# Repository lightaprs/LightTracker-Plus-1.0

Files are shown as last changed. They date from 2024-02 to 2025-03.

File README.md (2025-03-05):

# LightTracker Plus

LightTracker Plus is an ESP32-based development board featuring a 1 Watt SX1268 (433MHz) LoRa module, GPS module, battery holder, and 2 dBi 433 MHz SMA antenna.

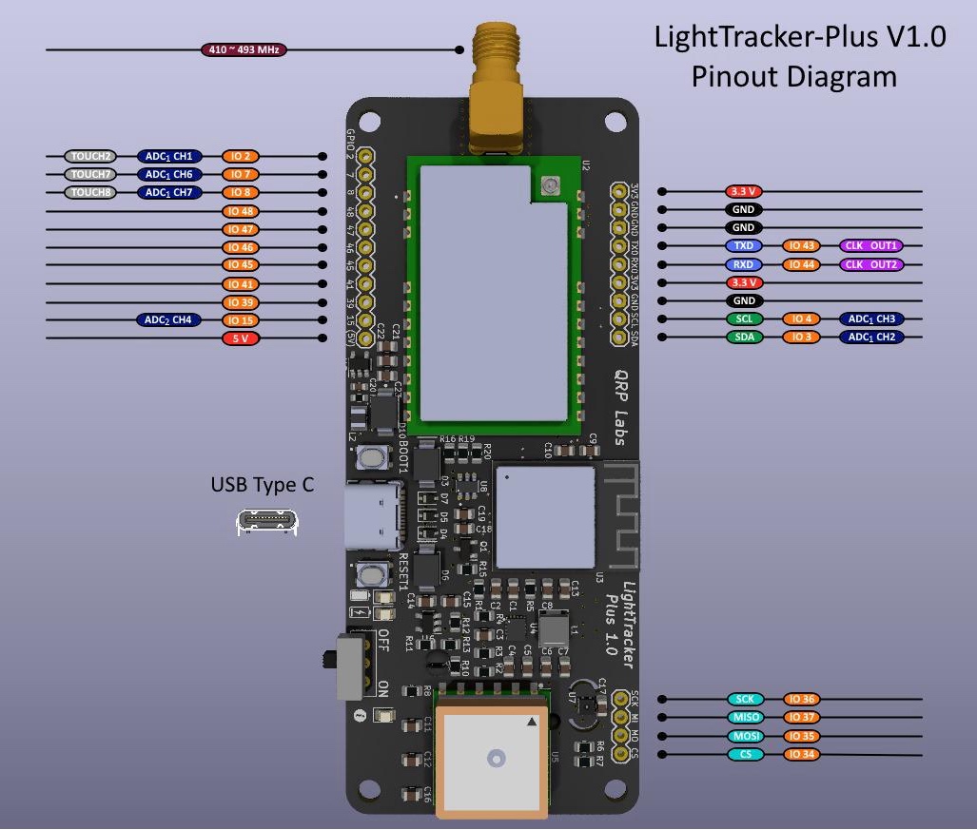
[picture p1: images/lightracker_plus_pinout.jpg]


LightTracker Plus is available on [https://shop.qrp-labs.com/aprs/lighttrackerplus](https://shop.qrp-labs.com/aprs/lighttrackerplus) for order.

If you need a Solar powered module for iGate or Digipeater check out : https://github.com/lightaprs/LightGatewayPlus-1.0

**Important :** LightTracker Plus 1.0 operates on the amateur 70 cm (UHF) radio band with a 30 dBm output power, which typically requires an amateur radio license to operate in many countries. Therefore, if you are not a licensed HAM operator, please ensure to check local regulations and laws before purchasing the module.

## Key Benefits

- Low Power Consumption Capability (Deep Sleep)
- Powerful (1 Watt) LoRa Radio Module
- Compact GPS Module Integrated with Patch Antenna
- GPS Balloon mode, for high altitude up to 80km (Convenient for High Altitude Balloon tracking)
- 18650 Battery Holder with charging capability (Battery not included)
- Suitable for Open Source HAM Radio ESP32 projects like Meshtastic, TinyGS, LoRa APRS Tracker & iGate, etc
- Shipped with preloaded basic [LoRa APRS Software](https://github.com/lightaprs/LightLoRaAPRS/)(Tracker, iGate or Digipeater) and supported by [Ricardo Guzman's LoRa APRS Tracker Software](https://github.com/richonguzman/LoRa_APRS_Tracker) You can use Web Flasher to install it -> https://richonguzman.github.io/lora-tracker-web-flasher/installer.html
  


- TinyGS compatible (still testing), check out [this page](https://github.com/lightaprs/tinyGS/wiki) for details.
- 0.96 inch OLED Screen (VCC,GND,SCL,SDA) support (OLED screen not included)
- 3D Models (stl files) for printing board case (Case not included)

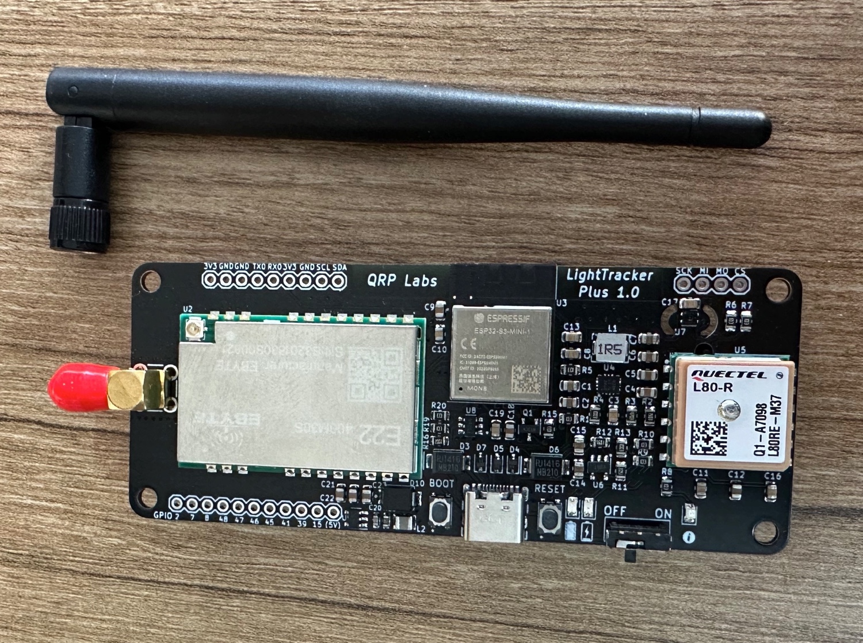
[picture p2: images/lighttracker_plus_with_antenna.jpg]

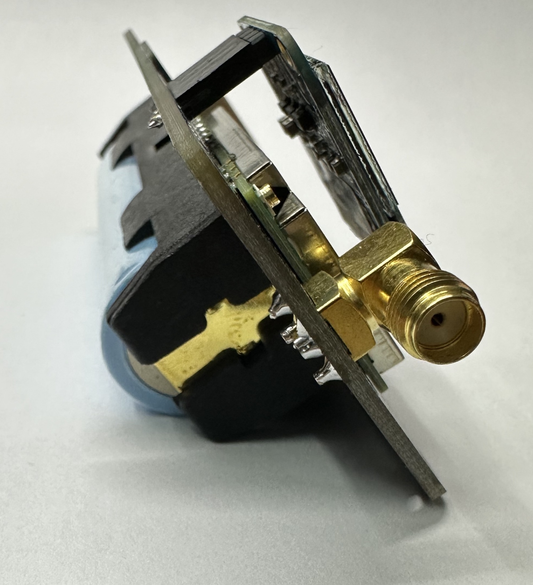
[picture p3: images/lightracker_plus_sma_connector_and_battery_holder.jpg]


## Basic Features

- **Software** : Open Source
- **Weight** : 40 grams
- **Dimensions** : 99.9 mm x 40.9 mm x 26 mm
- **IDE** : Arduino & VSCode
- **Platform** : ESP32
- **CPU** : ESP32-S3 MINI
- **Flash** : 8 MB
- **Ram** : 512 kB SRAM
- **Operating Frequency** : 240 Mhz
- **Operating Voltage** : 3.3 Volt
- **Input Voltage** : 3.3 (min) - 5.5 (max) Volt via USB Type C 2.0 or Battery Holder
- **Sensor** : SHTC3 (humidity and temperature)
- **Power Consumption (Deep Sleep)** : ~0.2 mA
- **Power Consumption (Idle)** : ~65 mA
- **LoRa Radio Module** : [EBYTE E22-400M30S](https://www.cdebyte.com/products/E22-400M30S) (SX1268)
- **LoRa Operating Frequency** : 410~493MHz (configurable by code)
- **LoRa Max Power** : 30dBm (configurable by code)
- **LoRa Power Consumption (TX)** : ~650 mA (30dBm)
- **GPS** : Quectel L80RE-M37 (GPS-QZSS)
- **Extended Pins** : I2C, I2S (in gpio pins, you can select random pins to use for I2S ), SPI, UART, 14x GPIO Pin(includes SPI, Analog pins, Touch pins), 4x Analog, 3x TOUCH, 2x CLK_OUT (in uart0 pins)

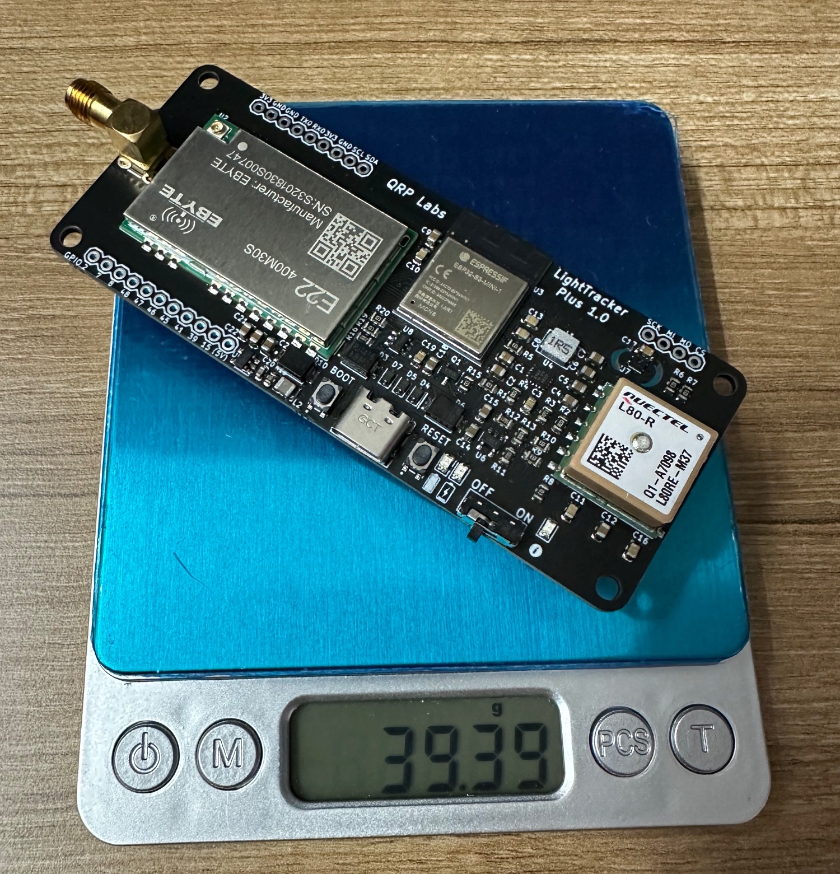
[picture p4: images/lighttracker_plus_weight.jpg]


## Support

If you have any questions or need support, please contact support@lightaprs.com

## Wiki

* **[F.A.Q.](https://github.com/lightaprs/LightTracker-Plus-1.0/wiki/F.A.Q.)**

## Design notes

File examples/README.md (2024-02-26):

To upload example sketch files to LightTracker Plus, all you need is a Type-C cable, Arduino IDE and configurations as follows:

### 1.Install Arduino IDE

Download and install [Arduino IDE](https://www.arduino.cc/en/Main/Software). If you have already installed Arduino, please check for updates. Its version should be at least v1.8.13 or newer.

### 2.Install ESP32 Arduino

- If you have installed ESP32 Arduino and upload any sketch file to any ESP32 board, skip this step...
- Open the Arduino IDE.
- Open the **File > Preferences** menu item.

Arduino_Preferences_Menu

- Enter the following URL in Additional Boards Manager URLs:
> https://espressif.github.io/arduino-esp32/package_esp32_index.json
- Separate the URLs using a comma ( , ) if you have more than one URL. Click **OK**.
- Open the **Tools > Board > Boards Manager...** menu item.
- Wait for the platform indexes to finish downloading.
- Type "ESP32" in the search bar until you see the **ESP32** entry and click on it and select latest version.

Arduino_Board_Manager_ESP32_Install

- Click **Install** .
- After installation is complete, close the **Boards Manager** window.

### 3.Configure ESP32

- Open the **Tools > Board** menu item and select **ESP32S3 Dev Module** from the end of the list.

lighttracker-plus-board-manager-esp32-s3-select
  
- After selecting **ESP32S3 Dev Module** you will see new options under **Tools** menu. Change these options as follows (keep the rest as is):
- USB CDC ON Boot: "Enabled"
- Flash Size: "8MB (64Mb)"
- Partition Scheme: "8M with spiffs (3MB APP/1.5MB SPIFFS)"

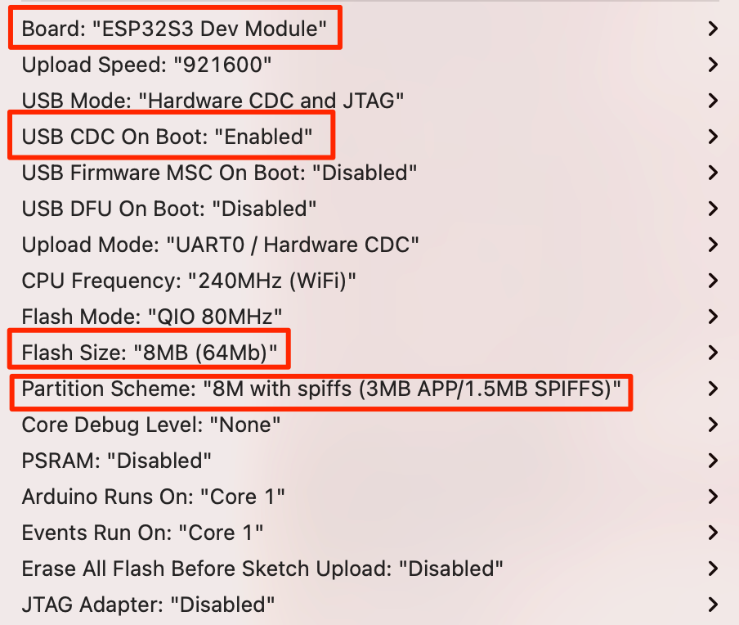
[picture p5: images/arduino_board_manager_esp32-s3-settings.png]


### 4.Copy Libraries & Compile Source Code 

You are almost ready to programme LightTracker Plus 1.0 :)

- First download the repository to your computer using the green "[Code -> Download ZIP](https://github.com/lightaprs/LightTracker-Plus-1.0/archive/refs/heads/main.zip)" button.
- You will notice some folders in the "libraries" folder. You have to copy these folders (libraries) into your Arduino libraries folder on your computer. Path to your Arduino libraries:
- **Windows** : This PC\Documents\Arduino\libraries\
- **Mac** : /Users/\<username\>/Documents/Arduino/libraries/

**IMPORTANT :** LightTracker Plus 1.0 uses more libraries than LightAPRS. So if you purchased LightAPRS and copied libraries before, do it again for LightTracker Plus 1.0. Otherwise you get a compile error.

- Then open the any *.ino file in the examples folder with Arduino IDE.
- Click **Verify** 

### 5.Upload

- First attach an UHF antenna to your module. Radio module may be damaged when not attaching an antenna, since power has nowhere to go. 
- Connect LightTracker Plus 1.0 to your computer with a Type-C cable.
- Holding down the **Boot** button than press the **Reset** button (and release both of them) to enable firmware upload mode.
  
- You should see a COM port under **Tools->Port** menu item. Select that port. 
- Click **Upload**

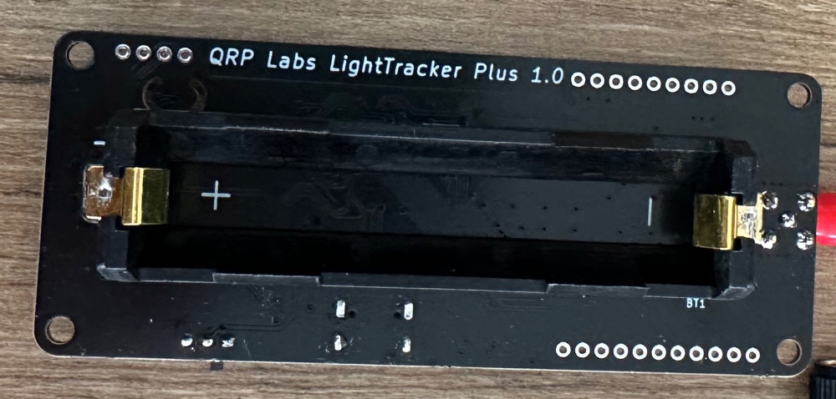
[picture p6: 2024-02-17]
images/lighttracker_plus_18650_battery_holder.jpg

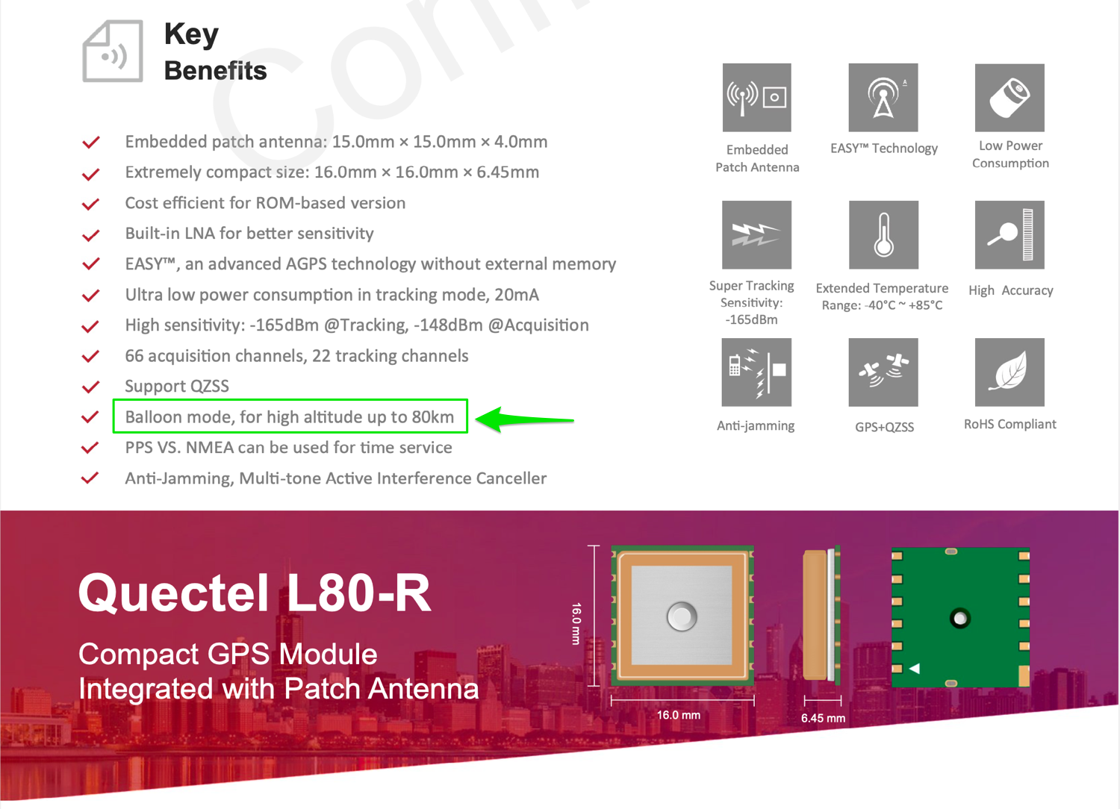
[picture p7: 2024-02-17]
images/Quectel_L80-R_gps_key_benefits.png

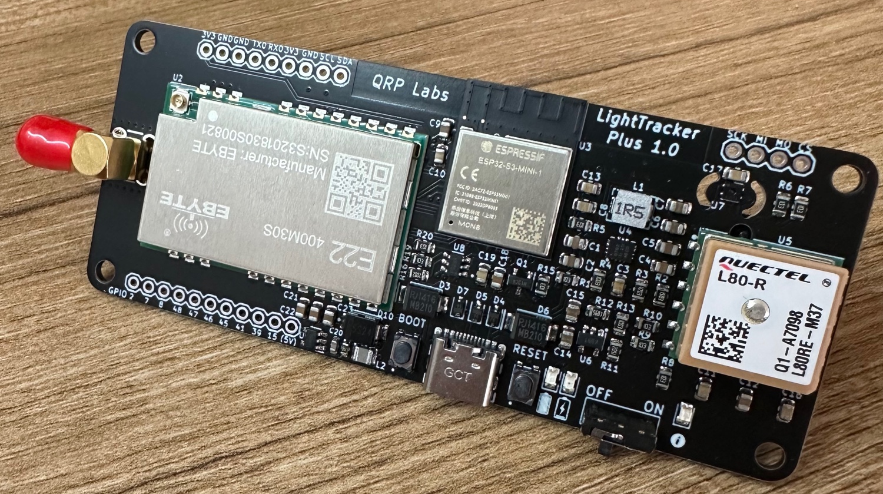
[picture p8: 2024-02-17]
images/lighttracker_plus_photo_side.jpg

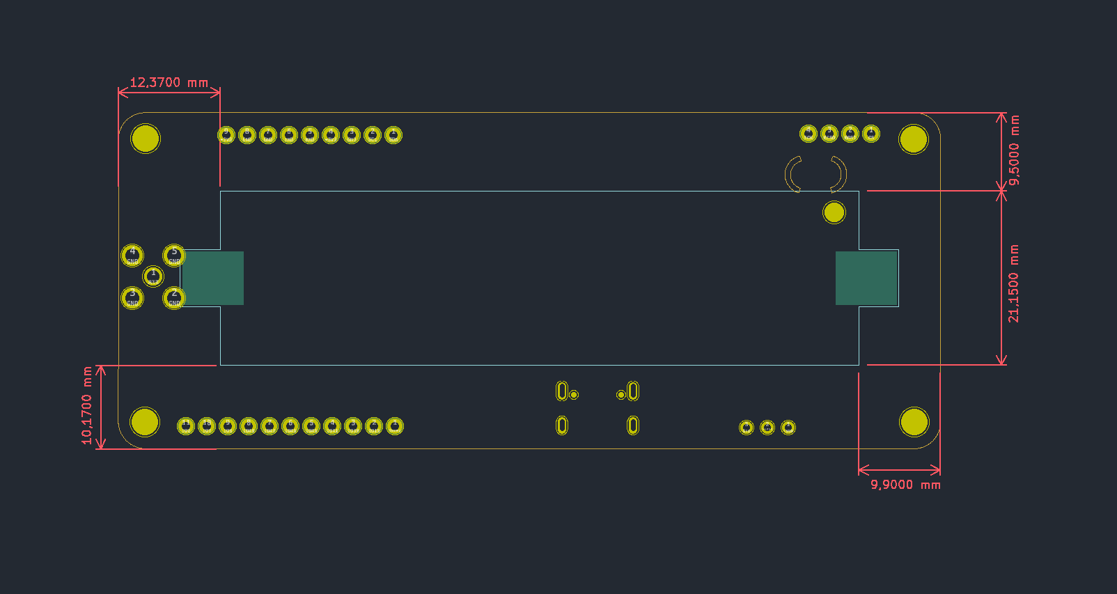
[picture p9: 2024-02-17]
images/lighttracker_plus_dimensions_back.png

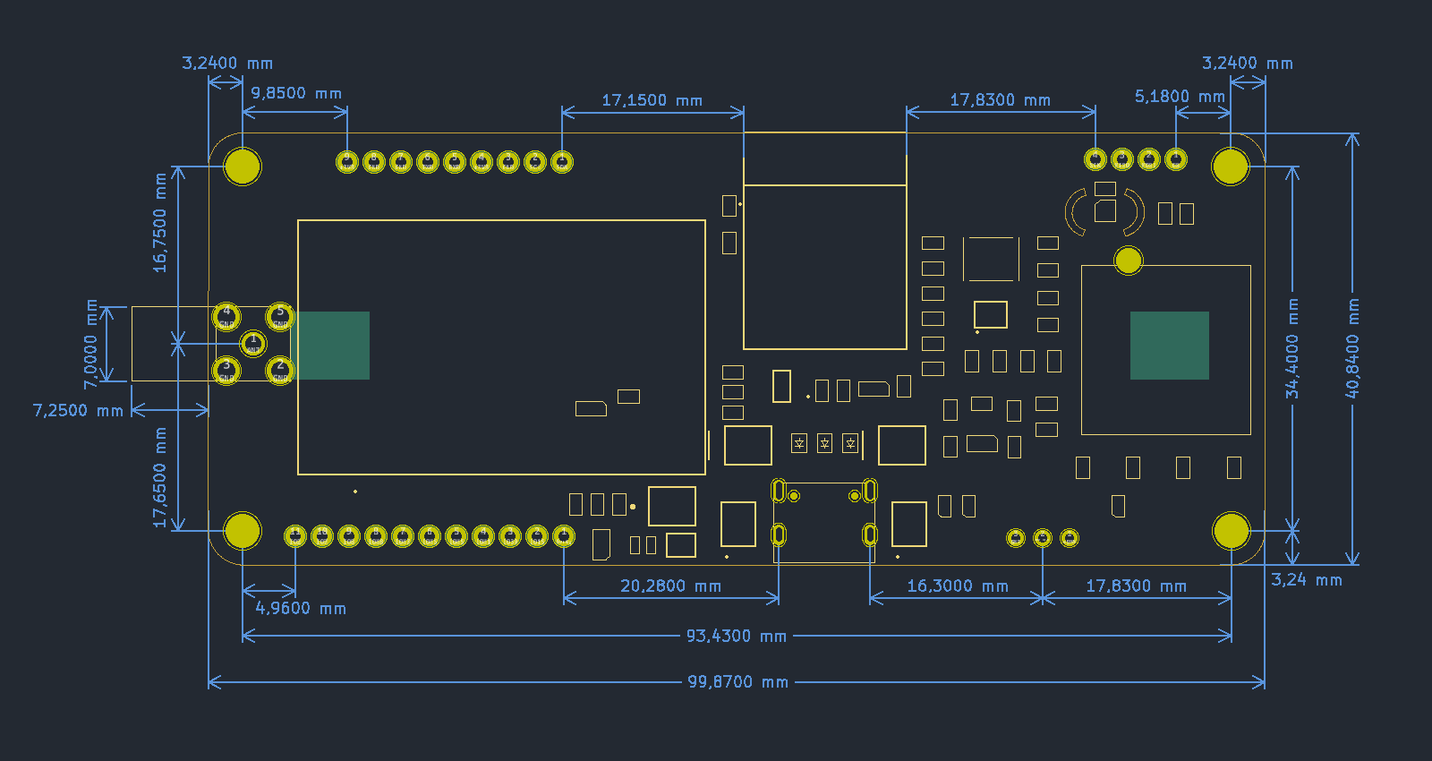
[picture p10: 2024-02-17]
images/lighttracker_plus_dimensions_front.png

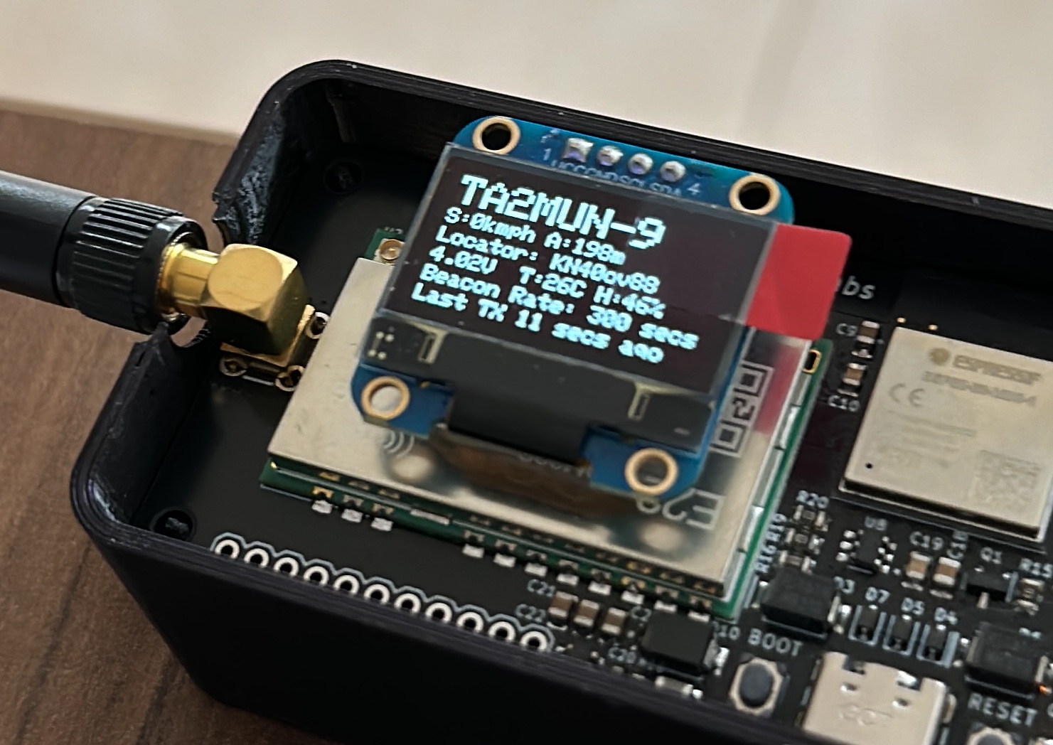
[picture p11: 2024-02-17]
images/lightracker_plus_oled_screen.jpg

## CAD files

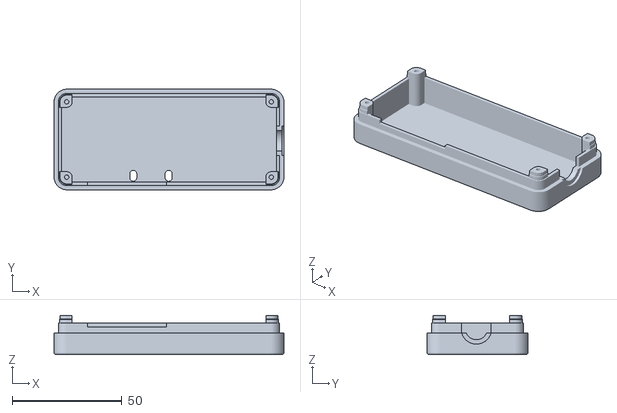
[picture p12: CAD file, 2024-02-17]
stl-files/light_tracker_plus_upper_case_without_screen_gap.stl
105.0 x 46.0 x 18.0

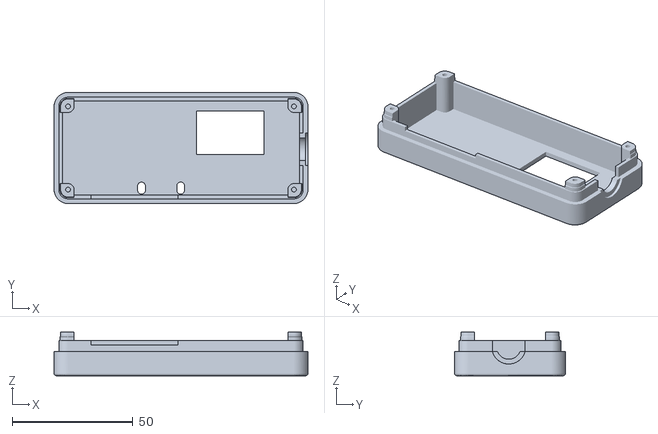
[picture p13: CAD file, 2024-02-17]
stl-files/light_tracker_plus_upper_case_with_screen_gap.stl
105.0 x 46.0 x 18.0

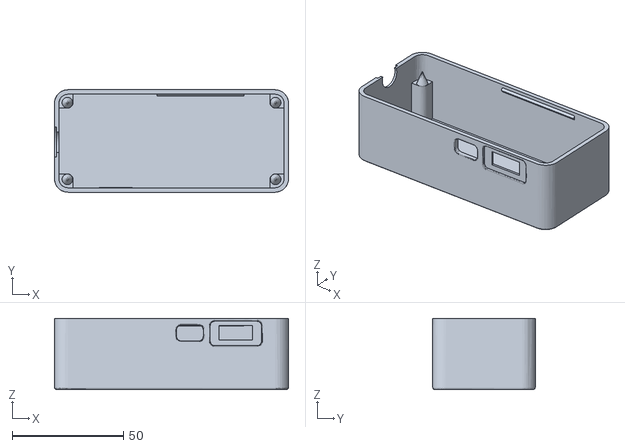
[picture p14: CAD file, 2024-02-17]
stl-files/light_tracker_plus_bottom_case.stl
105.0 x 46.0 x 32.0

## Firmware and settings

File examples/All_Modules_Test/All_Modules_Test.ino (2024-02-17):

#include "OneButton.h" //https://github.com/mathertel/OneButton/
#include <Adafruit_SSD1306.h>//https://github.com/adafruit/Adafruit_SSD1306
#include <Adafruit_GFX.h>//https://github.com/adafruit/Adafruit-GFX-Library and https://github.com/adafruit/Adafruit_BusIO
#include "SparkFun_SHTC3.h" //https://github.com/sparkfun/SparkFun_SHTC3_Arduino_Library
#include <TinyGPSPlus.h> //https://github.com/mikalhart/TinyGPSPlus
#include <RadioLib.h> //https://github.com/jgromes/RadioLib
#include "SPI.h"
#include <Wire.h>
#include <WiFi.h>
#include <WiFiClient.h>

#define BUTTON_PIN 0
#define LED_PIN 16
#define VOLTAGE_READ_PIN 1
#define ADC_MULTIPLIER 5.65
#define ADC_REFERENCE REF_3V3

#define SDA_PIN 3
#define SCL_PIN 4
#define OLED_RST_PIN -1
#define SCREEN_WIDTH    128     // OLED display width, in pixels
#define SCREEN_HEIGHT   64      // OLED display height, in pixels
#define SCREEN_ADDRESS  0x3C    ///< See datasheet for Address; 0x3D for 128x64, 0x3C for 128x32

#define GPS_SERIAL_NUM 1
#define GPS_BAUDRATE 9600
#define GPS_RX_PIN 18
#define GPS_TX_PIN 17
#define GPS_VCC_PIN 33
#define GpsON         digitalWrite(GPS_VCC_PIN, LOW)//PNP
#define GpsOFF        digitalWrite(GPS_VCC_PIN, HIGH)

//https://docs.rs-online.com/f450/0900766b8147dbe0.pdf
//https://www.mouser.com/datasheet/2/1052/Quectel_L80-R_GPS_Specification_V1.2-1830014.pdf
enum gps_pmtk_fr_modes {
  GPS_MODE_NORMAL,
  GPS_MODE_FITNESS,
  GPS_MODE_AVIATION,
  GPS_MODE_BALLOON
};

#define GPS_PMTK_FR_MODE_NORMAL_REQ     "$PMTK886,0*28"
#define GPS_PMTK_FR_MODE_FITNESS_REQ    "$PMTK886,1*29"
#define GPS_PMTK_FR_MODE_AVIATION_REQ   "$PMTK886,2*2A"
#define GPS_PMTK_FR_MODE_BALLOON_REQ    "$PMTK886,3*2B"

#define GPS_PMTK_FR_MODE_RESPONSE       "$PMTK001,886,3*36"

TinyGPSPlus gps;
HardwareSerial serialGPS(GPS_SERIAL_NUM);
unsigned long gpsLastProcessedTimeStamp = 0;
bool gps_fix_search_led = true;

uint16_t lastFetchedYear = 2100;
uint32_t lastFetchedSats = -1;
bool lastLocValid = false;

// uncomment the following only on one
// of the nodes to initiate the pings
#define INITIATING_NODE

#define SX126X_MAX_POWER 22 //22 is the max value for SX126X modules but E22-400M30S amplifies this to 30dBm. So do not change this.

#define LORA_VCC_PIN 21
#define LORA_RX_PIN 42
#define LORA_TX_PIN 14
#define LORA_SCK_PIN 12
#define LORA_MISO_PIN 13
#define LORA_MOSI_PIN 11
#define LORA_CS_PIN 10
#define LORA_RST_PIN 9
#define LORA_IRQ_PIN 5
#define LORA_BUSY_PIN 6

//******OneButton************/
OneButton btn;
static bool buttonPressed = false;

//*******Display************/
Adafruit_SSD1306 display(SCREEN_WIDTH, SCREEN_HEIGHT, &Wire, OLED_RST_PIN);

//****SHTC3*****/
SHTC3 mySHTC3;

//******LoRa************/
SPIClass loraSPI(FSPI);
SX1268 radio = new Module(LORA_CS_PIN, LORA_IRQ_PIN, LORA_RST_PIN, LORA_BUSY_PIN,loraSPI);  
// save transmission state between loops
int transmissionState = RADIOLIB_ERR_NONE;
// flag to indicate transmission or reception state
bool transmitFlag = false;
// flag to indicate that a packet was sent or received
volatile bool operationDone = false;
#if defined(ESP8266) || defined(ESP32)
  ICACHE_RAM_ATTR
#endif

void IRAM_ATTR checkTicks() {
  // keep watching the push button:
  btn.tick();
}

void setFlag(void) {
  // we sent or received a packet, set the flag
  operationDone = true;
}
int state;

//*********WI-FI Settings**********/
const char* ssid = "CHANGE_ME";
const char* password = "CHANGE_ME";


void setup() {
  Serial.begin(115200);
  delay(7000);
  Serial.println(F("Light Tracker Plus Full Test Started..."));
  
  pinMode(LED_PIN, OUTPUT);
  ledBlink(true);
  Serial.println(F("LED Blinked...[DONE]"));
  
  Wire.begin(SDA_PIN,SCL_PIN);
  Serial.println(F("Wire.begin()...[DONE]"));
  
  setup_Button();
  setupDisplay();
  setupGPS();
  setup_SHTC3Sensor();
  Serial.print(F("Voltage: "));Serial.println(readBatteryVoltage());
  setupLoRa();
  setupWiFi();


}

void loop() {
   btn.tick();
   updateGPSData();
   if(gps.satellites.value() != lastFetchedSats || gps.location.isValid() != lastLocValid || gps.date.year() < lastFetchedYear){
      lastFetchedSats = gps.satellites.value();
      lastFetchedYear = gps.date.year();
      lastLocValid = gps.location.isValid();
      printGPSData();
      printTempHumidity();
      Serial.print(F("Voltage: "));Serial.println(readBatteryVoltage());
    }
   if (!gps.location.isValid()){
      gpsSearchLedBlink();
    }

    loopLoRa();
    
    delay(100);
}

void setup_SHTC3Sensor()
{
    Serial.print(F("SHTC3 Temp & Humidity Sensor init..."));

    SHTC3_Status_TypeDef result = mySHTC3.begin();

    if(result==SHTC3_Status_Nominal){
        Serial.println(F("[DONE]"));
    } else {
        Serial.println(F("[DONE]"));
    }
    printTempHumidity();

}

void printTempHumidity(){
    SHTC3_Status_TypeDef result = mySHTC3.update(); 
    //SHTC3 sensor is not calibrated and readings are a little bit higher due to interal board heat.
    if(result==SHTC3_Status_Nominal){
          Serial.println("Temp: "+ String(mySHTC3.toDegC()) + "C Humiditiy(%): "+ String(mySHTC3.toPercent()));
    } else {
        Serial.print(F("SHTC3 temperature reading failed: ")); Serial.println(result);
    }      
  
  
  }

void setupGPS()
{
  pinMode(GPS_VCC_PIN,OUTPUT); 
  GpsON;
  delay(100);
  serialGPS.begin(GPS_BAUDRATE,SERIAL_8N1,GPS_RX_PIN,GPS_TX_PIN);
  Serial.println(F("GPS Begin...[DONE]"));
  delay(1000);
  updateGPSData();
  Serial.println(F("GPS Data Read...[DONE]"));
  bool modeChange = changeGPSMode(GPS_MODE_NORMAL);
  Serial.print(F("GPS Mode Change..."));
  if(modeChange) {
      Serial.println(F("[DONE]"));
    } else {
      Serial.println(F("[FAILED]"));
      }
}

bool changeGPSMode(u_int8_t cmdType) {
  bool result = false;

    switch (cmdType)
    {
    case GPS_MODE_NORMAL:
      Serial.println(F("GPS mode change request: NORMAL"));
      serialGPS.println(GPS_PMTK_FR_MODE_NORMAL_REQ);  
      break;
    case GPS_MODE_FITNESS:
      Serial.println(F("GPS mode change request: FITNESS"));
      serialGPS.println(GPS_PMTK_FR_MODE_FITNESS_REQ);
      break;
    case GPS_MODE_AVIATION:
      Serial.println(F("GPS mode change request: AVIATION"));
      serialGPS.println(GPS_PMTK_FR_MODE_AVIATION_REQ);    
      break;
    case GPS_MODE_BALLOON:
      Serial.println(F("GPS mode change request: BALLOON"));
      serialGPS.println(GPS_PMTK_FR_MODE_BALLOON_REQ);       
      break;
    default:
      return false;
      break;
    }
    serialGPS.flush();
    delay (250);
    String str="";
    char c;
    while (serialGPS.available() && !result) {
      c=serialGPS.read();
      str.concat(c);
      if ((str.indexOf(GPS_PMTK_FR_MODE_RESPONSE))!=-1) {
        //Serial.println(F("Mode change acknowledged by Quectel LXX GPS module..."));
        result = true;
      }      
    }
    
  return result;
}

void updateGPSData()
{
    while (serialGPS.available() > 0)
    {
        gps.encode(serialGPS.read());
    }

    if ((millis() - gpsLastProcessedTimeStamp) > 10000 && gps.charsProcessed() < 10)
    {
        Serial.println(F("GPS Data Read...[FAILED]"));
        while (true);
    }
    gpsLastProcessedTimeStamp = millis();

}

void printGPSData()
{

  Serial.print(F("Sats: ")); 
  if (gps.satellites.isValid())
  {
    Serial.print(gps.satellites.value());
  }
  else
  {
    Serial.print(F("INVALID"));
  }

  Serial.print(F(" Location: ")); 
  if (gps.location.isValid())
  {
    Serial.print(gps.location.lat(), 6);
    Serial.print(F(","));
    Serial.print(gps.location.lng(), 6);
  }
  else
  {
    Serial.print(F("INVALID"));
  }

  Serial.print(F(" Altitude: ")); 
  if (gps.altitude.isValid())
  {
    Serial.print(gps.altitude.meters());Serial.print(F("m"));
  }
  else
  {
    Serial.print(F("INVALID"));
  }    

  Serial.print(F(" Speed: ")); 
  if (gps.speed.isValid())
  {
    Serial.print((int)gps.speed.mph());
  }
  else
  {
    Serial.print(F("INVALID"));
  }  

  Serial.print(F(" Course: ")); 
  if (gps.course.isValid())
  {
    Serial.print((int)gps.course.deg());
  }
  else
  {
    Serial.print(F("INVALID"));
  }  

  Serial.print(F("  Date/Time: "));
  if (gps.date.isValid())
  {
    Serial.print(gps.date.month());
    Serial.print(F("/"));
    Serial.print(gps.date.day());
    Serial.print(F("/"));
    Serial.print(gps.date.year());
  }
  else
  {
    Serial.print(F("INVALID"));
  }

  Serial.print(F(" "));
  if (gps.time.isValid())
  {
    if (gps.time.hour() < 10) Serial.print(F("0"));
    Serial.print(gps.time.hour());
    Serial.print(F(":"));
    if (gps.time.minute() < 10) Serial.print(F("0"));
    Serial.print(gps.time.minute());
    Serial.print(F(":"));
    if (gps.time.second() < 10) Serial.print(F("0"));
    Serial.print(gps.time.second());
    Serial.print(F("."));
    if (gps.time.centisecond() < 10) Serial.print(F("0"));
    Serial.print(gps.time.centisecond());
  }
  else
  {
    Serial.print(F("INVALID"));
  }

  Serial.println();
}

void gpsSearchLedBlink(){
    if(gps_fix_search_led) {
      ledBlink(true);
      gps_fix_search_led = false;
    } else {
      ledBlink(false);
      gps_fix_search_led = true;
    }    
}


void setupWiFi(){
  WiFi.mode(WIFI_STA);
  WiFi.begin(ssid, password);
  Serial.print("Connecting to Wi-Fi");
  // Wait for connection
  while (WiFi.status() != WL_CONNECTED) {
    delay(500);
    Serial.print(".");
  }
  Serial.println("[DONE]");
  Serial.print("Connected to ");
  Serial.println(ssid);
  Serial.print("IP address: ");
  Serial.println(WiFi.localIP());  
}

void setupDisplay() {

  Serial.print(F("SSD1306 Display init..."));

  if(display.begin(SSD1306_SWITCHCAPVCC, SCREEN_ADDRESS)) {
    display.clearDisplay();
    display.setTextColor(WHITE);
    display.setTextSize(2);
    display.setCursor(0, 0);
    display.print("DONE!");  
    display.ssd1306_command(SSD1306_SETCONTRAST);
    display.ssd1306_command(1);
    display.display();
    delay(500);
    Serial.println(F("[DONE]"));  
  } else {
    Serial.println(F("[FAILED]"));
  }
    
}

void ledBlink(bool enabled) {
  if(enabled) {
    digitalWrite(LED_PIN, HIGH);
  } else {
    digitalWrite(LED_PIN, LOW);
  }
}

void setup_Button()
{
  pinMode(BUTTON_PIN, INPUT_PULLUP);
  btn = OneButton(
  BUTTON_PIN, // Input pin for the button
  true,       // Button is active LOW
  true       // Enable internal pull-up resistor
  );
  attachInterrupt(digitalPinToInterrupt(BUTTON_PIN), checkTicks, CHANGE);
  btn.attachClick(singleClick);
  btn.attachDoubleClick(doubleClick);
  Serial.println(F("BOOT Button Setup...[DONE]"));
}

void singleClick() {
    Serial.println(F("Button pressed once"));
}

void doubleClick() {
    Serial.println(F("Button pressed twice"));
}

void loopLoRa(){
  // check if the previous operation finished
  if(operationDone) {
    // reset flag
    operationDone = false;

    if(transmitFlag) {
      // the previous operation was transmission, listen for response
      // print the result
      if (transmissionState == RADIOLIB_ERR_NONE) {
        // packet was successfully sent
        Serial.println(F("[SX1268] LoRa Packet Sent [DONE]"));

      } else {
        Serial.print(F("failed, code "));
        Serial.println(transmissionState);
      }
      digitalWrite(LORA_TX_PIN,LOW); //TX DISABLE
      digitalWrite(LORA_RX_PIN,HIGH); //RX ENABLE
      delay(100);
      // listen for response
      radio.startReceive();
      transmitFlag = false;

    } else {
      // the previous operation was reception
      // print data and send another packet
      String str;
      int state = radio.readData(str);

      if (state == RADIOLIB_ERR_NONE) {
        // packet was successfully received
        Serial.println(F("[SX1268] Received packet!"));

        // print data of the packet
        Serial.print(F("[SX1268] Data:\t\t"));
        Serial.println(str);

        // print RSSI (Received Signal Strength Indicator)
        Serial.print(F("[SX1268] RSSI:\t\t"));
        Serial.print(radio.getRSSI());
        Serial.println(F(" dBm"));

        // print SNR (Signal-to-Noise Ratio)
        Serial.print(F("[SX1268] SNR:\t\t"));
        Serial.print(radio.getSNR());
        Serial.println(F(" dB"));

      }

      /**
      delay(5000);
      digitalWrite(LORA_TX_PIN,HIGH); //TX ENABLE
      digitalWrite(LORA_RX_PIN,LOW);  //RX DISABLE
      delay(100);
      // send another one
      Serial.print(F("[SX1268] Sending another packet ... "));
      transmissionState = radio.startTransmit("Light Tracker Plus Test Loop Message");
      transmitFlag = true;
      */
    }
  
  }  
}

void setupLoRa()
{
    pinMode(LORA_VCC_PIN,OUTPUT);  
    pinMode(LORA_TX_PIN,OUTPUT);
    pinMode(LORA_RX_PIN,OUTPUT);

    digitalWrite(LORA_VCC_PIN,HIGH);
    delay(500);

    loraSPI.begin(LORA_SCK_PIN,LORA_MISO_PIN,LORA_MOSI_PIN,LORA_CS_PIN);

    // initialize LoRa Radio Module with default settings
    Serial.print(F("LoRa Radio Module Initializing..."));
    state = radio.begin();
    if (state == RADIOLIB_ERR_NONE) {
        Serial.println(F("[DONE]"));
    } else {
        Serial.println(F("[FAILED!]"));    
        while (true);
    }

    digitalWrite(LORA_TX_PIN,HIGH); //TX ENABLE
    digitalWrite(LORA_RX_PIN,LOW);  //RX DISABLE

   // set carrier frequency to 433.775 MHz
    if (radio.setFrequency(433.775) == RADIOLIB_ERR_INVALID_FREQUENCY) {
      Serial.println(F("Selected frequency is invalid for this module!"));
      while (true);
    }
      
    // set bandwidth to 125 kHz
    if (radio.setBandwidth(125.0) == RADIOLIB_ERR_INVALID_BANDWIDTH) {
      Serial.println(F("Selected bandwidth is invalid for this module!"));
      while (true);
    }
  
    // set spreading factor to 12
    if (radio.setSpreadingFactor(12) == RADIOLIB_ERR_INVALID_SPREADING_FACTOR) {
      Serial.println(F("Selected spreading factor is invalid for this module!"));
      while (true);
    }
  
    // set coding rate to 5
    if (radio.setCodingRate(5) == RADIOLIB_ERR_INVALID_CODING_RATE) {
      Serial.println(F("Selected coding rate is invalid for this module!"));
      while (true);
    }
  
    // set LoRa sync word
    if (radio.setSyncWord(RADIOLIB_SX126X_SYNC_WORD_PRIVATE) != RADIOLIB_ERR_NONE) {
      Serial.println(F("Unable to set sync word!"));
      while (true);
    }
  
    // set LoRa preamble length to 8 symbols (accepted range is 0 - 65535)
    if (radio.setPreambleLength(8) == RADIOLIB_ERR_INVALID_PREAMBLE_LENGTH) {
      Serial.println(F("Selected preamble length is invalid for this module!"));
      while (true);
    }
  
    // disable CRC
    if (radio.setCRC(false) == RADIOLIB_ERR_INVALID_CRC_CONFIGURATION) {
      Serial.println(F("Selected CRC is invalid for this module!"));
      while (true);
    }
  
     // set output power to 22 dBm (accepted range is -17 - 22 dBm)
    if (radio.setOutputPower(22) == RADIOLIB_ERR_INVALID_OUTPUT_POWER) {
      Serial.println(F("Selected output power is invalid for this module!"));
      while (true);
    }
  
    // set over current protection limit to 140 mA (accepted range is 45 - 140 mA)
    // NOTE: set value to 0 to disable overcurrent protection
    if (radio.setCurrentLimit(140.0) == RADIOLIB_ERR_INVALID_CURRENT_LIMIT) {
      Serial.println(F("Selected current limit is invalid for this module!"));
      while (true);
    }

    // set the function that will be called
    // when new packet is received
    radio.setDio1Action(setFlag);    
  
    #if defined(INITIATING_NODE)
      // send the first packet on this node
      Serial.println(F("[SX1268] Sending first packet ... "));
      transmissionState = radio.startTransmit("Light Tracker Plus Full Test Message");
      transmitFlag = true;
    #else
      // start listening for LoRa packets on this node
      Serial.println(F("[SX1268] Starting to listen ... "));
      state = radio.startReceive();
      if (state == RADIOLIB_ERR_NONE) {
        Serial.println(F("success!"));
      } else {
        Serial.print(F("failed, code "));
        Serial.println(state);
        while (true);
      }
    #endif
}

double readBatteryVoltage() {

  u_int8_t num_samples = 10;
  int sum = 0;             
  u_int8_t sample_count = 0;

  while (sample_count < num_samples) {
    sum += analogRead(VOLTAGE_READ_PIN);
    sample_count++;
    delay(10);
  }

  int reading_average = sum / num_samples;

  if(reading_average < 1 || reading_average > 4095) return 0;

  float voltage = ADC_MULTIPLIER * (-0.000000000000016 * pow(reading_average,4) + 0.000000000118171 * pow(reading_average,3)- 0.000000301211691 * pow(reading_average,2)+ 0.001109019271794 * reading_average + 0.034143524634089);

  return voltage;
}

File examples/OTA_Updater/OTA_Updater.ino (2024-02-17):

/*
  -----------------------
  ElegantOTA - Demo Example
  -----------------------

  Skill Level: Beginner

  This example provides with a bare minimal app with ElegantOTA functionality.

  Github: https://github.com/ayushsharma82/ElegantOTA
  WiKi: https://docs.elegantota.pro

  Works with following hardware:
  - ESP8266
  - ESP32
  - RP2040 (with WiFi) (Example: Raspberry Pi Pico W)


  Important note for RP2040 users:
  - RP2040 requires LittleFS partition for the OTA updates to work. Without LittleFS partition, OTA updates will fail.
    Make sure to select Tools > Flash Size > "2MB (Sketch 1MB, FS 1MB)" option.
  - If using bare RP2040, it requires WiFi module like Pico W for ElegantOTA to work.

  -------------------------------

  Upgrade to ElegantOTA Pro: https://elegantota.pro

*/


#if defined(ESP8266)
  #include <ESP8266WiFi.h>
  #include <WiFiClient.h>
  #include <ESP8266WebServer.h>
#elif defined(ESP32)
  #include <WiFi.h>
  #include <WiFiClient.h>
  #include <WebServer.h>
#elif defined(TARGET_RP2040)
  #include <WiFi.h>
  #include <WebServer.h>
#endif

#include <ElegantOTA.h>

const char* ssid = "MODEM_SSID";
const char* password = "SSID_PASSWORD";

#if defined(ESP8266)
  ESP8266WebServer server(80);
#elif defined(ESP32)
  WebServer server(80);
#elif defined(TARGET_RP2040)
  WebServer server(80);
#endif

unsigned long ota_progress_millis = 0;

void onOTAStart() {
  // Log when OTA has started
  Serial.println("OTA update started!");
  // <Add your own code here>
}

void onOTAProgress(size_t current, size_t final) {
  // Log every 1 second
  if (millis() - ota_progress_millis > 1000) {
    ota_progress_millis = millis();
    Serial.printf("OTA Progress Current: %u bytes, Final: %u bytes\n", current, final);
  }
}

void onOTAEnd(bool success) {
  // Log when OTA has finished
  if (success) {
    Serial.println("OTA update finished successfully!");
  } else {
    Serial.println("There was an error during OTA update!");
  }
  // <Add your own code here>
}

void setup(void) {
  Serial.begin(115200);
  delay(5000);
  WiFi.mode(WIFI_STA);
  WiFi.begin(ssid, password);
  Serial.println("ElegantOTA started...");
  Serial.print("Connecting to Wi-Fi");
  // Wait for connection
  while (WiFi.status() != WL_CONNECTED) {
    delay(500);
    Serial.print(".");
  }
  Serial.println("");
  Serial.print("Connected to ");
  Serial.println(ssid);
  Serial.print("IP address: ");
  Serial.println(WiFi.localIP());

  server.on("/", []() {
    server.send(200, "text/plain", "Hi! This is ElegantOTA Demo.");
  });

  ElegantOTA.begin(&server);    // Start ElegantOTA
  // ElegantOTA callbacks
  ElegantOTA.onStart(onOTAStart);
  ElegantOTA.onProgress(onOTAProgress);
  ElegantOTA.onEnd(onOTAEnd);

  server.begin();
  Serial.println("HTTP server started");
  Serial.print("http://");Serial.print(WiFi.localIP());Serial.print("/update");
}

void loop(void) {
  server.handleClient();
  ElegantOTA.loop();
}
